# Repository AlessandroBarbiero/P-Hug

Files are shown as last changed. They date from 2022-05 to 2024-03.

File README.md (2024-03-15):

# P'Hug
This repository contains code, wiring schemas, manuals, and a development report on the creation of a wearable robot.  
The delivery was: Make a wearable robot able to engage interactions with third people.

## Abstract
According to surveys and research the haptic sense is a significant aspect of human wellbeing. The experience received as a result of contact with another living creature like hugs stimulates serotonin production. High serotonin levels improve mood, make people feel better, and help having better sleep. Nowadays people are more linked than ever before as a result of the developing trend of technology. While technology has helped to bridge the gap, it has not been able to eliminate all the barriers imposed by distance. Our initiative primarily aims to bridge this gap by creating a product that sends a haptic hug from one device (Giffy: the puppet) to another one (the Jacket). The embrace and caress from the puppet is transfered via a wifi connection to the wearer of the jacket. The wearer can feel three major sensations: vibration achieved by vibration motors simulating a moving caress, pressure from an inflatable chamber simulating a hug, and a constant warm feeling from a resistive wire. Our goal is not to replace an actual embrace, but to help people that live apart and cannot hold their loved ones having a fraction of that so desired contact.

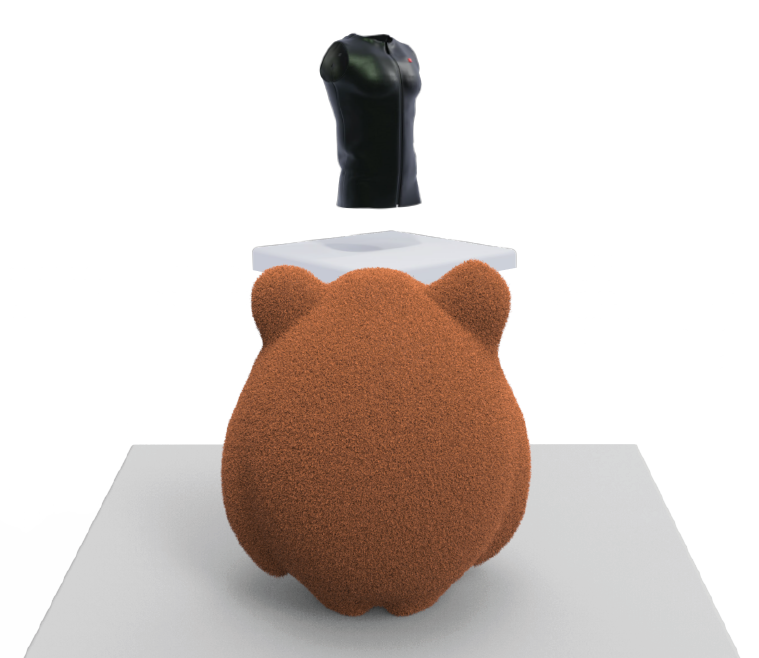
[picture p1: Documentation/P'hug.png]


## More Informations

> P'Hug [Instructions Manual](/Documentation/P'Hug%20Instructions.pdf)

> P'Hug [Maintenance Manual](/Documentation/P'Hug%20Maintenance.pdf)

> Complete [Report](/Documentation/Report%20P'Hug.pdf) of the Development Process

## Electronics organization
Here are reported the wiring schemas for the two devices
### `Giffy`
Built around an `Arduino Mkr1000 wifi`

Input:
- 3 Force sensitive resistors to simulate the caress
- Force sensitive resistor to simulate the hug
- Accelerometer to detect shaking
- NFC reader to upload SSID and Password using the Application

Output:
- 2 Servo motors to move the ears
- Speaker
- Integrated Wifi module (ATSAMW25) of Arduino Mkr1000 wifi

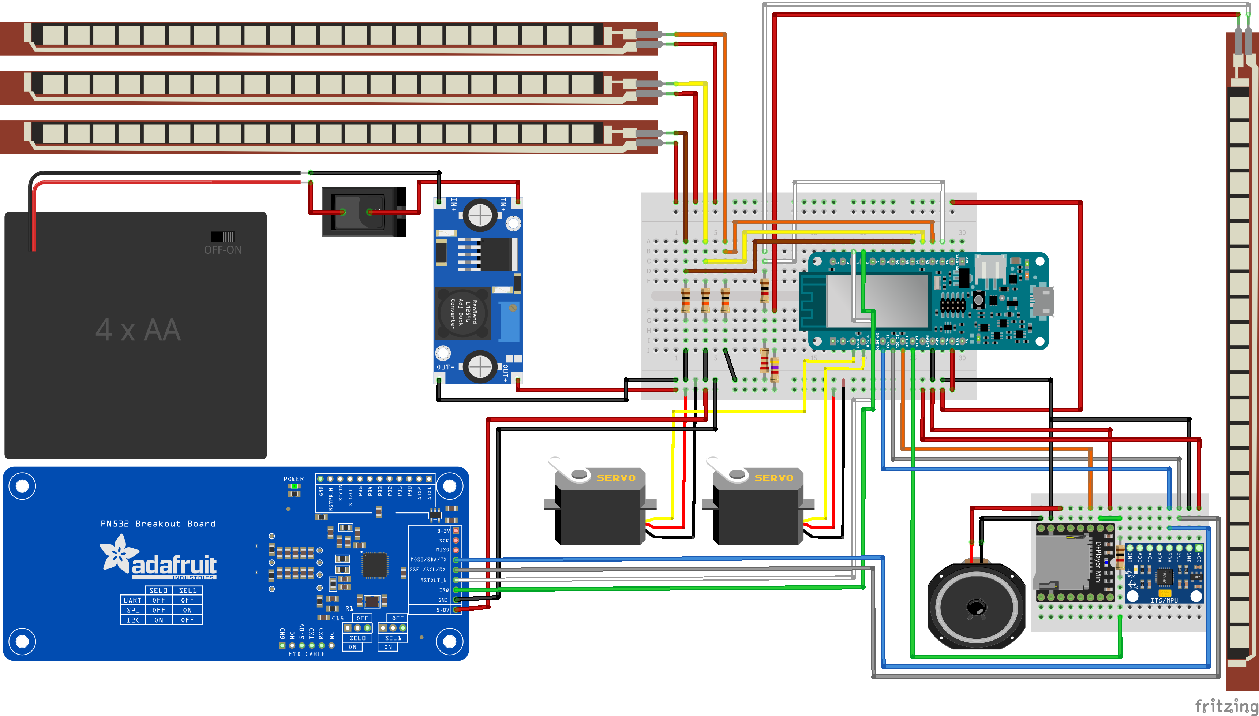
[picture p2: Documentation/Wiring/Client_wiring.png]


##

### `The Jacket`
Built around an `Adafruit Feather Huzzah`

Input:
- Integrated Wifi module (ESP8266) of Adafruit Feather Huzzah 
- Bluetooth module (HC-05) to upload SSID and Password

Output:
- 6 Vibration motors to simulate the caress
- Air pump to inflate the chamber around the waist to simulate the hug
- Heating resistance activated via a relè

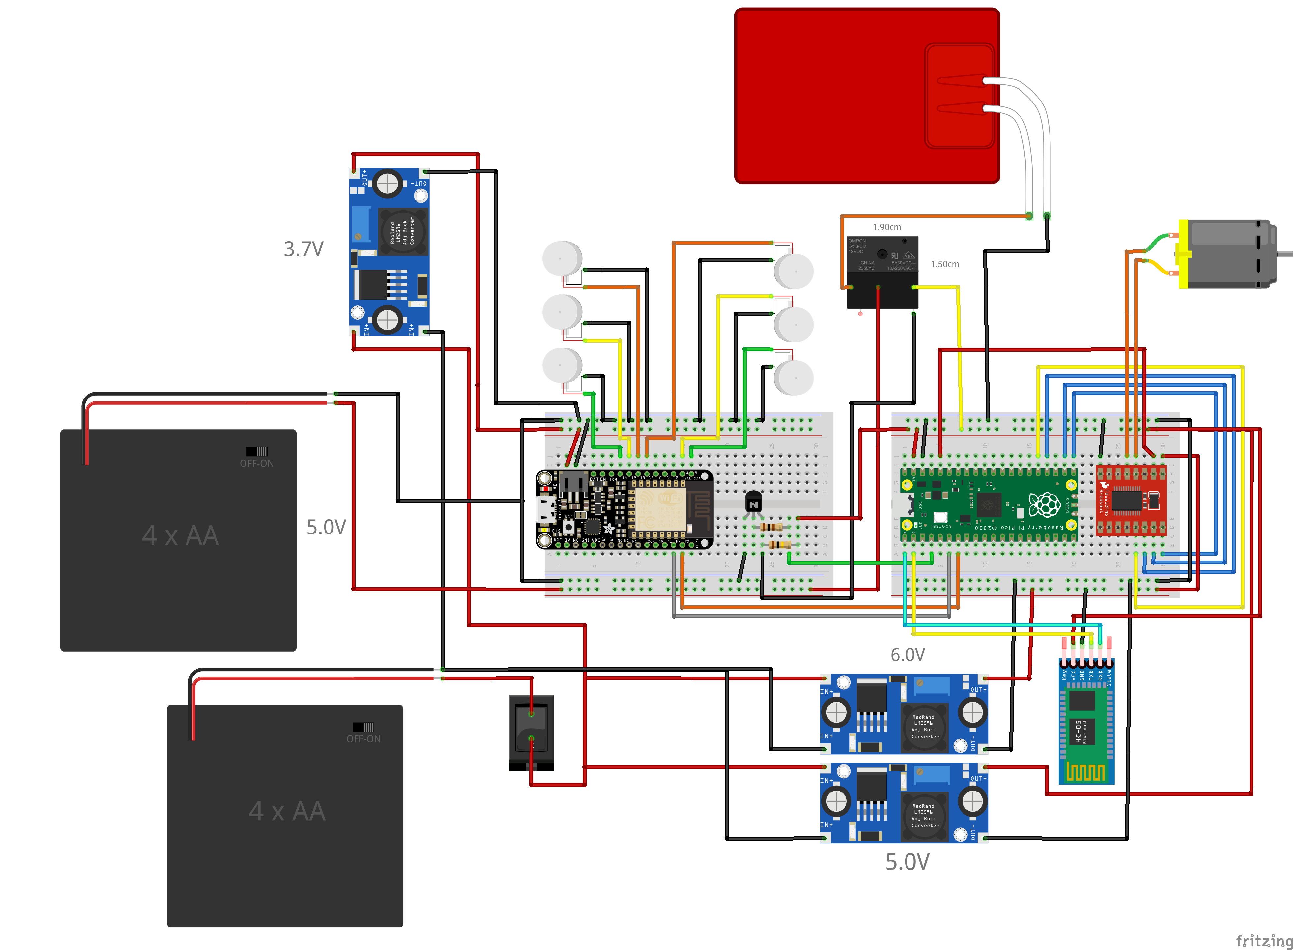
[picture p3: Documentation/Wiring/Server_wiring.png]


## Code organization
All the code has been written following the object oriented programming model with the help of the platform `PlatformIO`.
The main idea is to build a client-server model to receive the information from Giffy and send it to the jacket that operates according to that.

The code can be seen in the folders [Client](/Client/) for Giffy and [Server](/Server/) for the Jacket.

## How to run the project
1. Clone the repository
    ```bash
    git clone https://github.com/AlessandroBarbiero/P-Hug.git
    ```

2. Download an IDE (suggested [PlatformIO](https://platformio.org/) for `Visual Studio Code`).

3. Open the folder [Client](/Client/) or [Server](/Server/Server%20Huzzah/) as `PlatformIO project` from the PlatformIO home.

4. Click on `PlatformIO:upload` on the bottom left.

5. Download the app from the folder [App](/App/) (Read the specific readme for more information about it)

## Team

  

### Engineers

* [__Alessandro Barbiero__](https://github.com/AlessandroBarbiero)
* [__Luigi Altamura__](https://github.com/LuigiAltamura)
* [__Lorenzo Poretti__](https://github.com/lap98)
* [__Elias Insulander__](https://github.com/eliasinsulander)

### Designers

* __Lorenzo Dondi__
* __Helen Berhanu Tekle__

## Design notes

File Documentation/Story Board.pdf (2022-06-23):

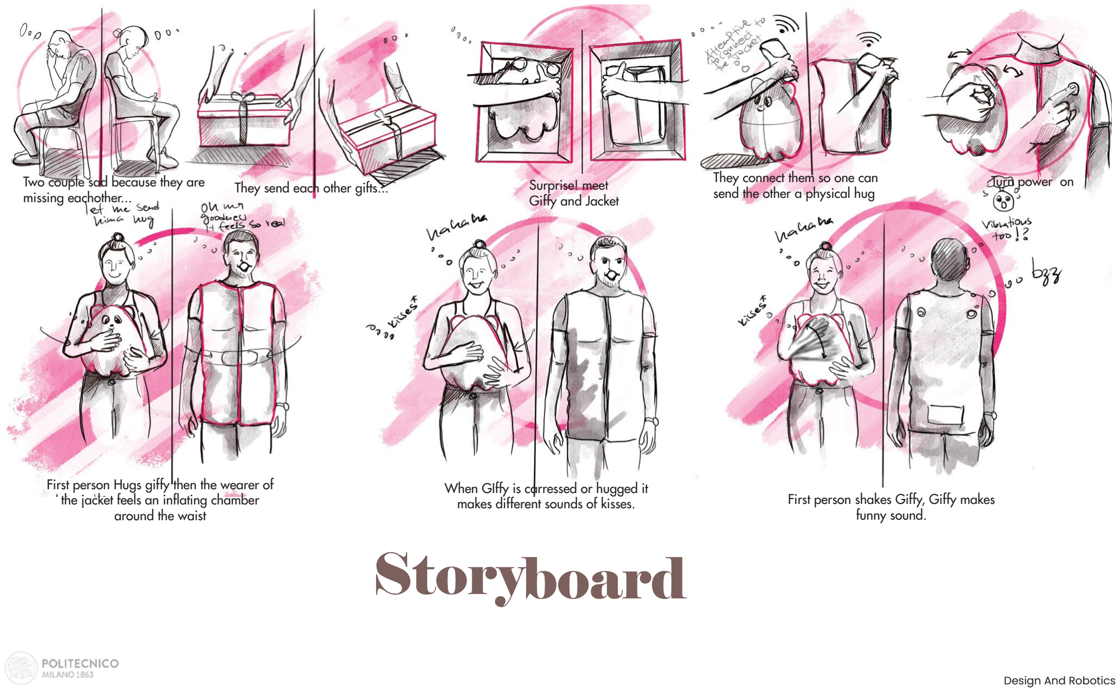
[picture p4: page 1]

# Storyboard

Two couple sad because they are
missing eachother... | They send each other gifts... | Surprise! meet
| | Giffy and Jacket

Turn power on They connect them so one can send the other a physical hug

When GIffy is carressed or hugged it
makes different sounds of kisses. | First person shakes Giffy, Giffy makes
| funny sound.

First person Hugs giffy then the wearer of the jacket feels an inflating chamber around the waist

Design And Robotics

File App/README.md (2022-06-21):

# apP-HUG

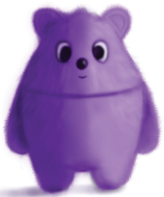
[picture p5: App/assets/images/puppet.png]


apP-HUG is an application to provide network data to Giffy using NFC in an easy way

## Installation

Download the application from this link:

[apP-HUG](https://github.com/AlessandroBarbiero/Robotics-and-Design-project/blob/main/App/APK/apP-HUG.apk)

During installation you may encounter warnings informing you that the application may not be safe. This is because the application is not uploaded to the Google Play Store. 

Accept all the conditions, install it and you now should see a screen like this:

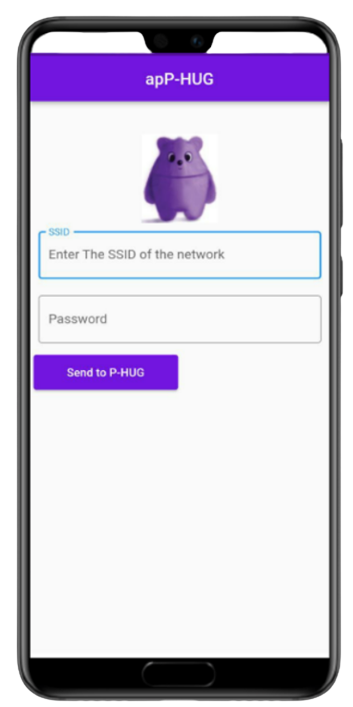
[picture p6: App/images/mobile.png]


## How to use the app 

Before turning on the robot:

- Open the application, activate your hotspot/wifi and NFC in your mobile phone 

- Add SSID of the network in the first text field and the password in the second textfield (username and password have to be maximum 15 characters lenght each)

- Press the send message

- Put your cell phone close to the Giffy's head and wait untill the NFC is red (you should notice a vibration)

Now you are ready! Enjoy GIFFY !!!

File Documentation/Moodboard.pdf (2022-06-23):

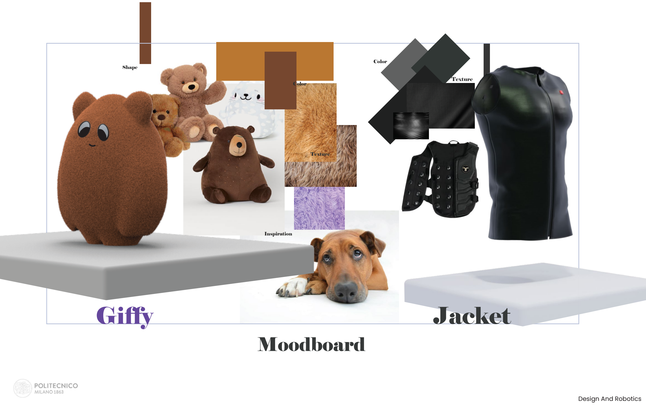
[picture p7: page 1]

Shape

Color

Color

Texture

Texture

# Giffy

Inspiration

# Jacket

# Moodboard

## Design And Robotics

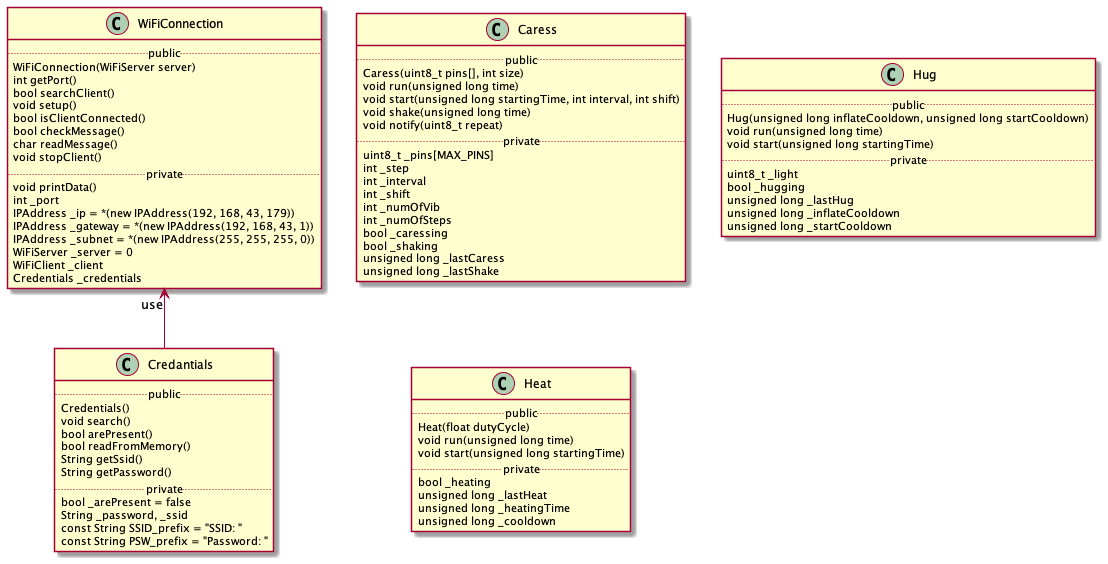
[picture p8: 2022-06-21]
Server/Server Huzzah/diagrams/server.png

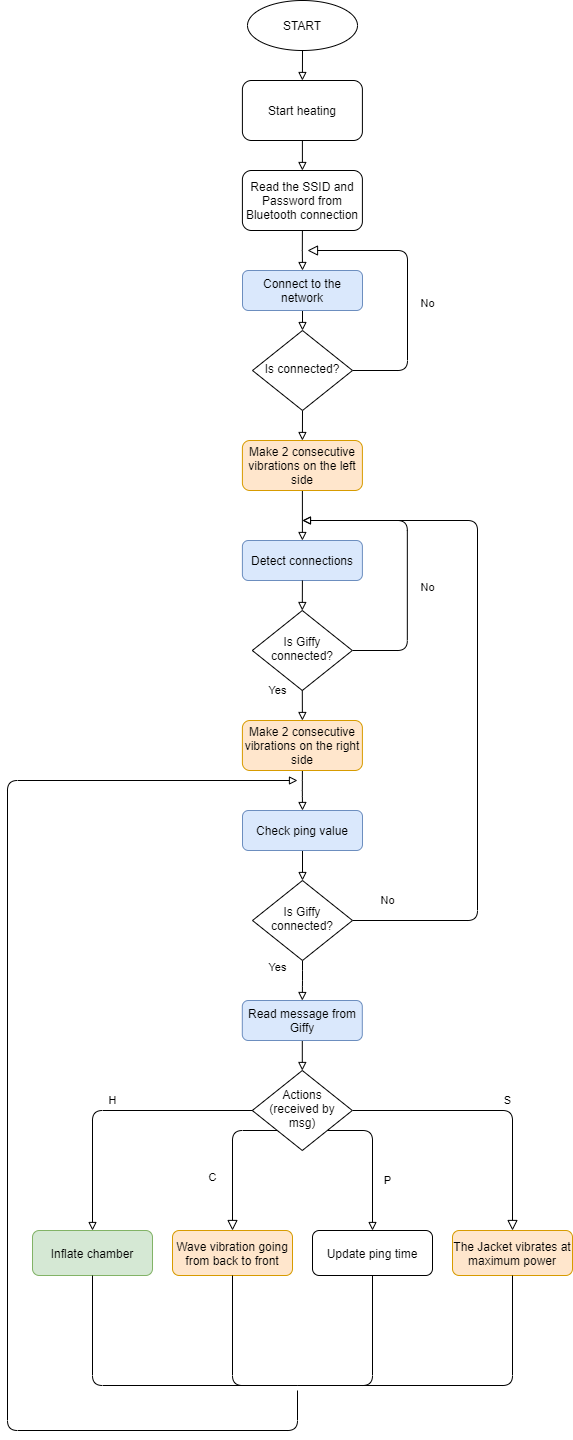
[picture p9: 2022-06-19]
Documentation/Flowchart/Flowchart_Jacket.png

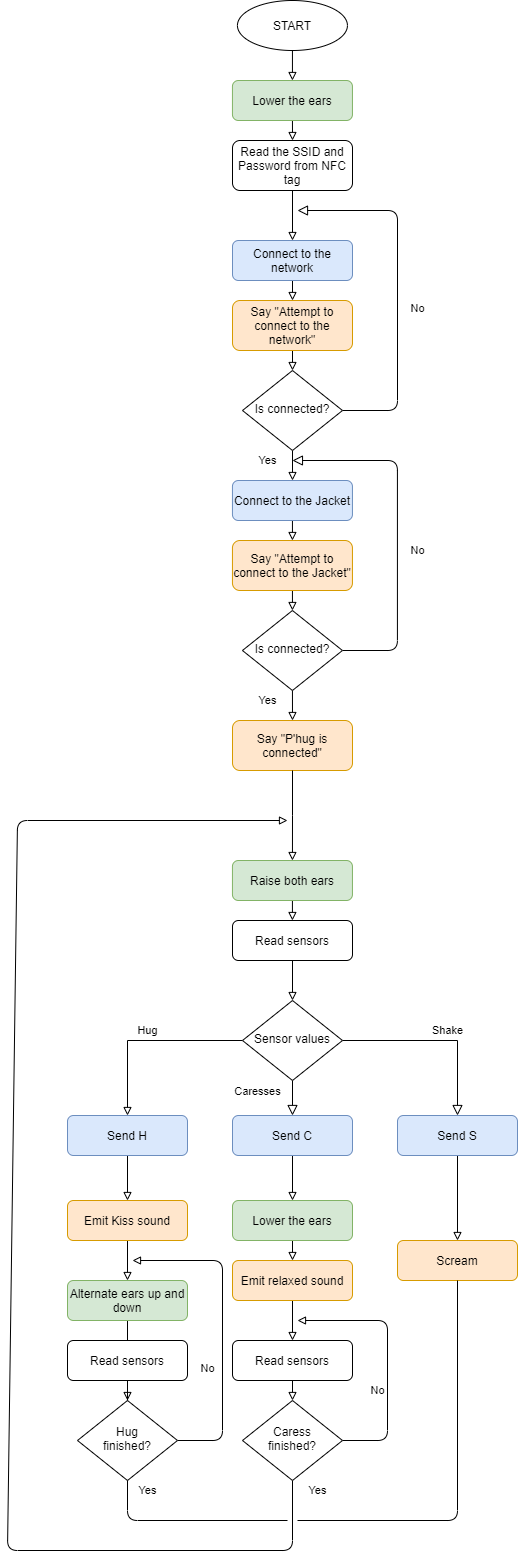
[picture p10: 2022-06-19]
Documentation/Flowchart/Flowchart_Giffy.png

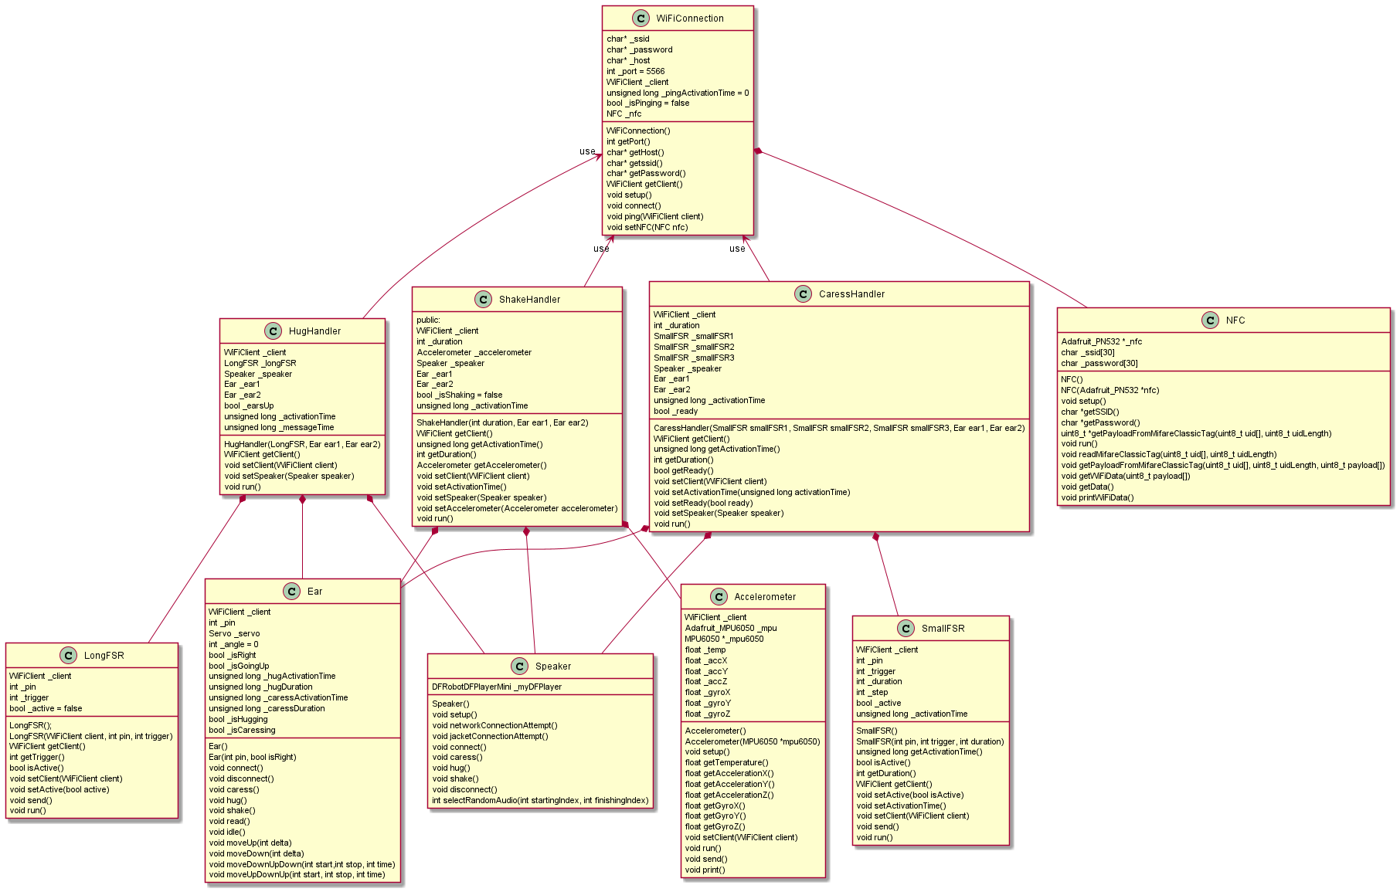
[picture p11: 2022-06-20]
Client/out/diagrams/diagram/diagram.png

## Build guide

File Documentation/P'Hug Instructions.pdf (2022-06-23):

# P-HUG

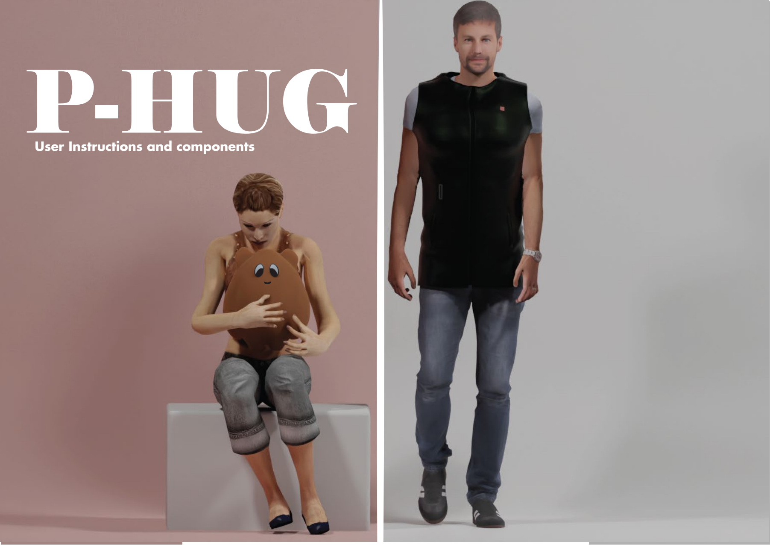
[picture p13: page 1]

## User Instructions and components

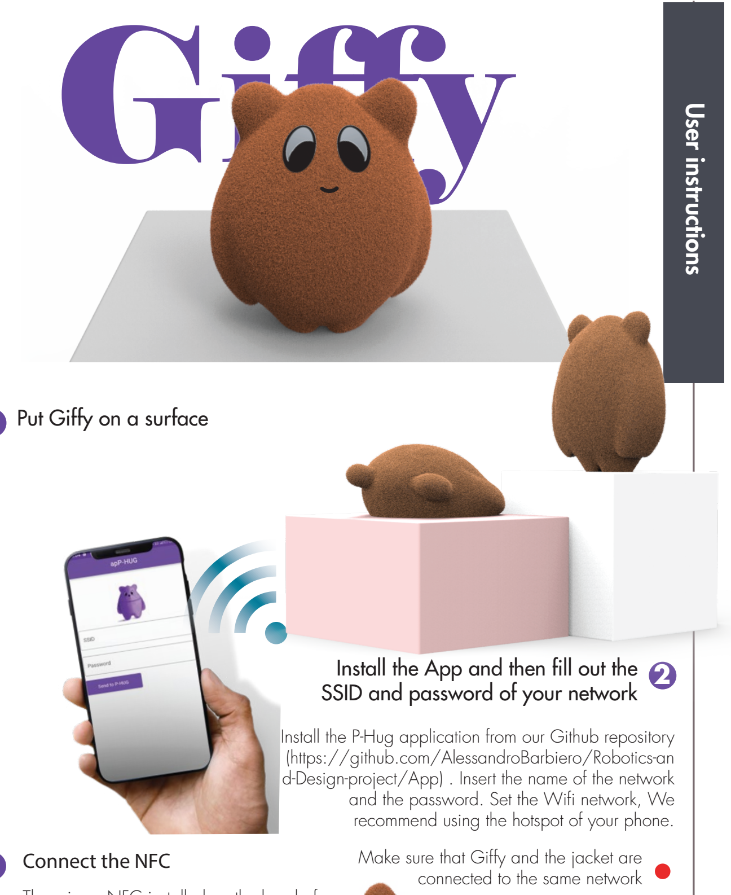
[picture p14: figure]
Giffy; Connect the NFC; Put Giffy on a surface; User instructions; (https://github.com/AlessandroBarbiero/Robotics-an; Make sure that Giffy and the jacket are connected to the same network; Install the App and then fill out the SSID and password of your network

1

3

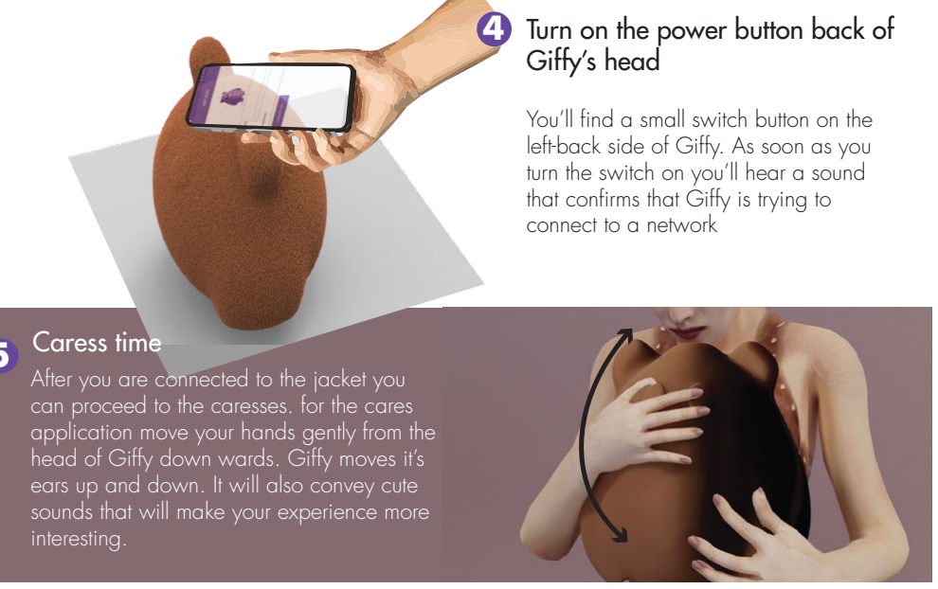
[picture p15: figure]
Turn on the power button back of Giffy’s head; left-back side of Giffy. As soon as you turn the switch on you’ll hear a sound that confirms that Giffy is trying to connect to a network; interesting.; Caress time

You’ll find a small switch button on the

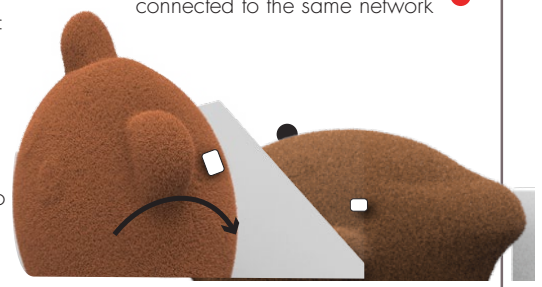
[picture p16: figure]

There is an NFC installed on the head of Giffy. Hoover your smartphone close to Giffy's head, after connecting with the NFC Giffy will make sure that you are connected with the Jacket, you will hear a message that says “attempting to connect with the jacket”. You will listen to a sound that says “P-Hug is connected”

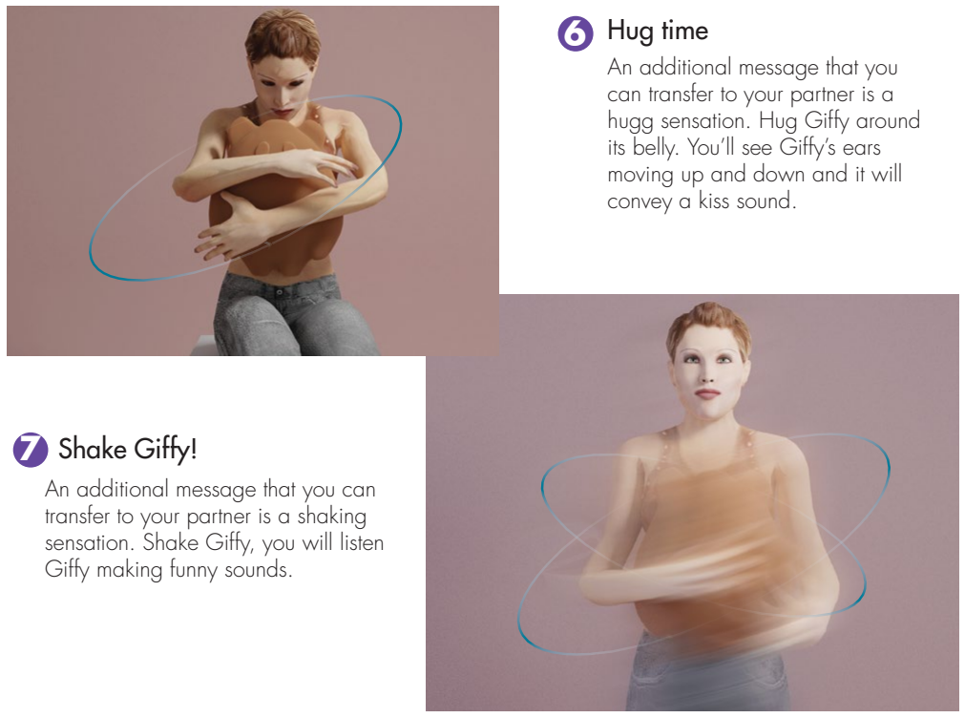
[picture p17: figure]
An additional message that you can transfer to your partner is a hugg sensation. Hug Giffy around its belly. You’ll see Giffy’s ears moving up and down and it will convey a kiss sound.; An additional message that you can transfer to your partner is a shaking sensation. Shake Giffy, you will listen Giffy making funny sounds.; Hug time; Shake Giffy!

# Design And Robotics

5
After you are connected to the jacket you can proceed to the caresses. for the cares application move your hands gently from the head of Giffy down wards. Giffy moves it’s ears up and down. It will also convey cute sounds that will make your experience more

Install the P-Hug application from our Github repository

d-Design-project/App) . Insert the name of the network and the password. Set the Wifi network, We recommend using the hotspot of your phone.

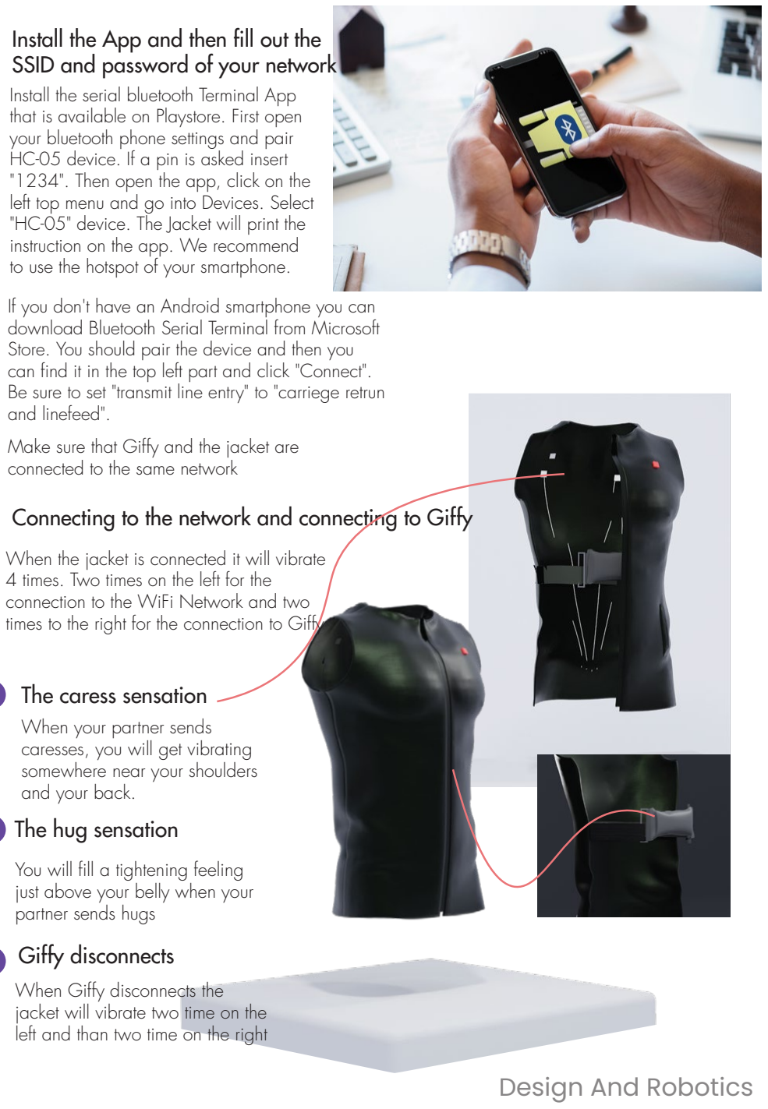
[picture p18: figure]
SSID and password of your network; Make sure that Giffy and the jacket are connected to the same network; When Giffy disconnects the jacket will vibrate two time on the left and than two time on the right; 4 times. Two times on the left for the connection to the WiFi Network and two
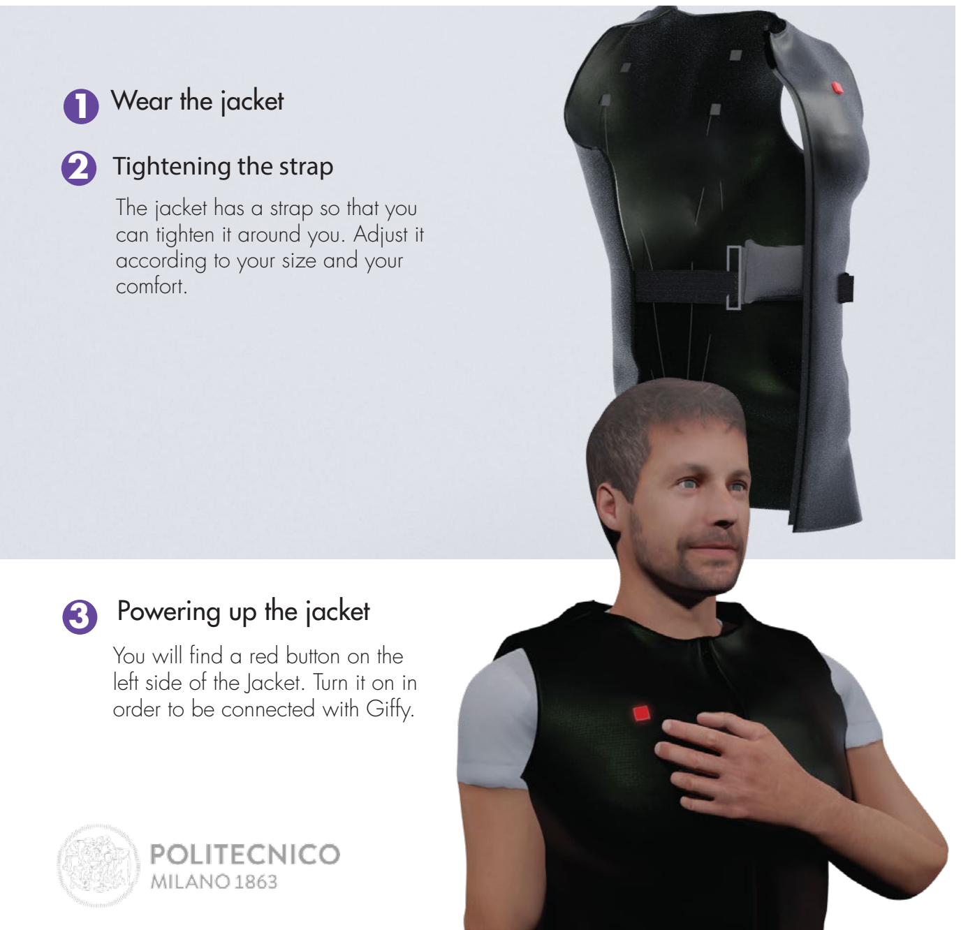
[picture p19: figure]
Powering up the jacket; Wear the jacket; The jacket has a strap so that you can tighten it around you. Adjust it according to your size and your comfort.; You will find a red button on the left side of the Jacket. Turn it on in order to be connected with Giffy.; 2 Tightening the strap 13

When your partner sends
caresses, you will get vibrating somewhere near your shoulders and your back.

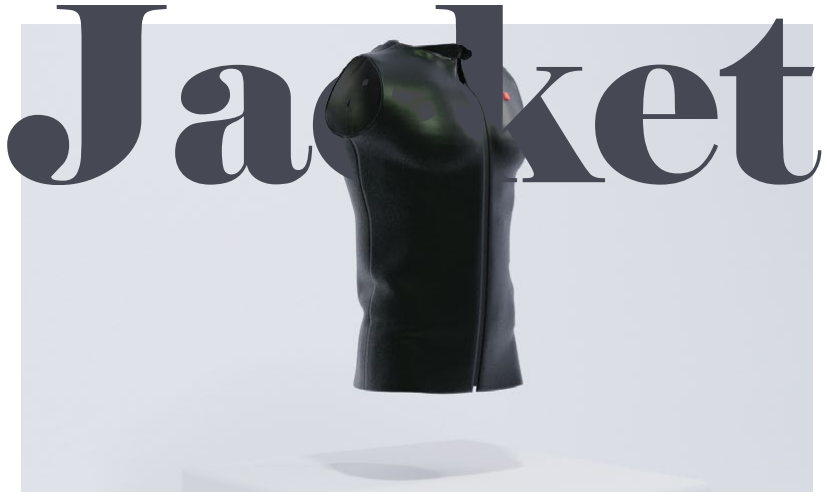
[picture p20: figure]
Jacket

## User instructions

### The hug sensation

### Giffy disconnects

You will fill a tightening feeling just above your belly when your partner sends hugs

### 6 The caress sensation

### Connecting to the network and connecting to Giffy

78

Install the serial bluetooth Terminal App that is available on Playstore. First open your bluetooth phone settings and pair HC-05 device. If a pin is asked insert "1234". Then open the app, click on the left top menu and go into Devices. Select "HC-05" device. The Jacket will print the instruction on the app. We recommend
to use the hotspot of your smartphone.

If you don't have an Android smartphone you can download Bluetooth Serial Terminal from Microsoft Store. You should pair the device and then you can find it in the top left part and click "Connect". Be sure to set "transmit line entry" to "carriege retrun and linefeed".

### Install the App and then fill out the

45

When the jacket is connected it will vibrate

times to the right for the connection to Giffy

Giffy Components | Description

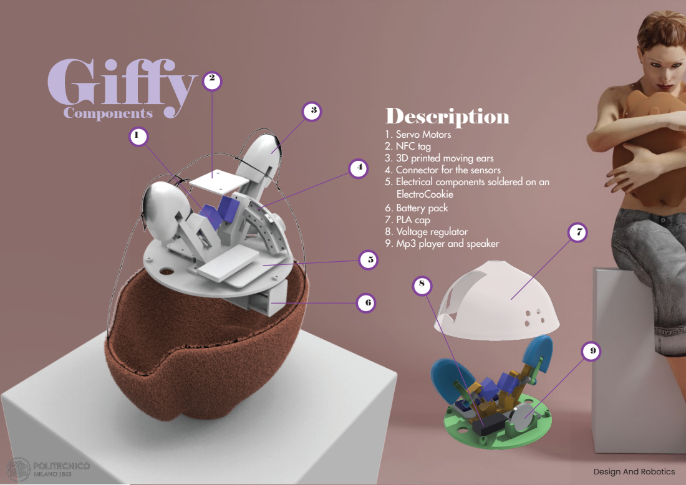
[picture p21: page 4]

1. Servo Motors
2. NFC tag
3. 3D printed moving ears
4. Connector for the sensors
5. Electrical components soldered on an
ElectroCookie
6. Battery pack
7. PLA cap
8. Voltage regulator
9. Mp3 player and speaker

# Jacket

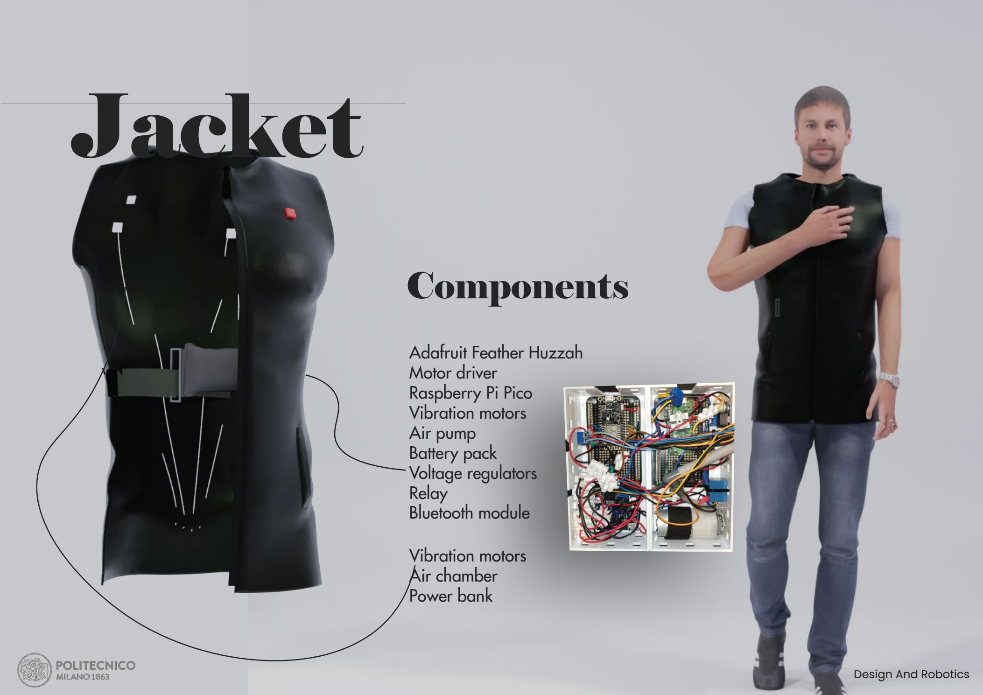
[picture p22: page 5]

## Vibration motors Air chamber Power bank

# Components

## Adafruit Feather Huzzah Motor driver Raspberry Pi Pico Vibration motors Air pump Battery pack Voltage regulators Relay Bluetooth module

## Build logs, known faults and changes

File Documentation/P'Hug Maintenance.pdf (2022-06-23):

# P’Hug - Maintenance instructions

Below, you can find some maintenance instructions if there is an issue with either the puppet or the jacket. Most parts can be replaced and these parts are connected to the respective boards via wire connectors that can be tightened/loosened using a screwdriver. If a part needs further instructions for replacement it is specified under “Specific parts”.

## Giffy

For all Giffy part replacements and access to the board:
1. Open the zip on the back of the puppet
2. Remove the soft stuffing inside the puppet
3. Carefully pull out the long force sensor from the guides
4. Carefully take out the head of the puppet with all of the electronics
5. Perform the required maintenance
6. Carefully put everything back in the puppet (reverse steps 1-4)

### Power

Replacing the batteries of the puppet can be done without removing the puppets head from the puppets body. In order to change the batteries of Giffy:
1. Pull out the battery pack on the bottom of the head
2. Remove the 4 AA-batteries from the battery pack
3. Insert new batteries in the battery pack
4. Reinsert battery pack into the holder on the bottom of the head

### Part replacement

For all part replacements:
1. Remove the three screws fixing the dome to the plate of the head
2. Disassemble the ears by separating the two ear parts (one ear could be enough, but easier with both removed)
3. Remove the dome from the plate
4. Disconnect the wires for the desired part
5. Connect new part
6. Reassemble the head (reverse steps 1-3)

Specific parts:
The servo motors, the speaker and the NFC are all soldered directly to the board, and in order to change these parts resoldering is necessary.

### Access to board

To access the board in order to upload code and/or debug:
1. Remove the three screws fixing the dome to the plate of the head
2. Disassemble the ears by separating the two ear parts (one ear could be enough, but easier with both removed)
3. Remove the dome from the plate
4. Connect a Micro-USB cable to the Arduino MKR1000
5. Upload/debug code
6. Disconnect the Micro-USB cable
7. Reassemble the head (reverse steps 1-3)

## Jacket

For all jacket part replacements and access to the boards:
1. Remove the bands over the box on the back of the jacket
2. Carefully pull the wires connected to the box out from the jacket slightly
3. Remove the smaller elastic bands around the box
4. Remove the plate from the box and turn the box so that the electronics are exposed.
5. Perform the required maintenance
6. Put everything back in its place (reverse steps 1-4)

### Power

In the left hand pocket of the jacket there is a USB-connected power bank. This power bank can be recharged and/or replaced with another power bank of the same characteristics. The power bank is used only to power the heating part of the jacket, you can easily disconnect this power bank in order to not feel the heating sensation. The maximum current allowed is 2.1A, and we are using a power bank with capacity of 16750mAh.

In the right hand pocket of the jacket there is a battery pack. It powers all the electronics. In order to change the batteries of the battery pack:
1. Take the battery pack out of the pocket
2. Open the battery pack
3. Remove the 4 AA-batteries
4. Insert new batteries in the battery pack
5. Close the battery pack
6. Reinsert the battery pack into the pocket

### Part replacement

For all part replacements:
1. Disconnect the wires for the desired part
2. Connect new part

Specific parts:
The vibration motors are sewn onto the inside of the jacket and must be detached and resewn in order to replace them. They can be easily accessed via the zips on the inside of the jacket.

The air pump and air chamber was originally from a sphygmomanometer and we don’t recommend that they be changed, as the code is tuned specifically for this air pump and this air chamber.

We also don’t recommend that you replace the heating system, as it was integrated in the jacket when we received it.

### Access to boards

The Micro-USB ports of the two boards are easily accessible even when the box is closed, though it is recommended to open the box when uploading or debugging code.
1. Connect a Micro-USB cable to the Adafruit Feather HUZZAH and/or the Raspberry Pi Pico
a. If code has to be uploaded to the Adafruit Feather HUZZAH, also disconnect one of the serial communication wires (TX) connected to the Raspberry Pi Pico (the gray one) unscrewing the screw on the connector
2. Upload/debug code
a. If code was uploaded to the Adafruit Feather HUZZAH, also reconnect the serial communication wire to the Raspberry Pi Pico
3. Disconnect the Micro-USB cable

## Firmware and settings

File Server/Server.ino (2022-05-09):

#include "arduino_secrets.h"
#include <ESP8266WiFi.h>

// Define Pins
#define VIB1 14
#define VIB2 12
#define VIB3 13
#define MAX 255
#define BUTTON A0
#define COOLDOWN 10000
#define INTERVAL 510
#define HINTERVAL 255
#define SHIFT 255
#define NROFVIB 3
int val,i;
unsigned long lastCaress,lastHug;
bool caressing,hugging;

///////please enter your sensitive data in the Secret tab/arduino_secrets.h
char ssid[] = SECRET_SSID;        // your network SSID (name)
char pass[] = SECRET_PASS;    // your network password (use for WPA, or use as key for WEP)
int status = WL_IDLE_STATUS;     // the Wifi radio's status
// mac address for M-Duino

int data = 0;
int tcp_port = 5566;
IPAddress ip(192, 168, 43, 179); 
IPAddress gateway(192, 168, 43, 1);
IPAddress subnet(255, 255, 255, 0);
WiFiServer server(tcp_port);
void setup() {
  //Vibration init
  pinMode(VIB1, OUTPUT);
  pinMode(VIB2, OUTPUT);
  pinMode(VIB3, OUTPUT);
  pinMode(0, OUTPUT);
  digitalWrite(0, HIGH);
  Serial.begin(9600);
  lastCaress = 0;
  caressing = false;
  hugging = false;
  
  //Initialize serial and wait for port to open:
  Serial.begin(9600);

  WiFi.config(ip, gateway, subnet);
  while (!Serial);
  
  // attempt to connect to Wifi network:
  while (status != WL_CONNECTED) {
    Serial.print("Attempting to connect to network: ");
    Serial.println(ssid);
    // Connect to WPA/WPA2 network:
    status = WiFi.begin(ssid, pass);

    // wait 10 seconds for connection:
    delay(10000);
    
  }
  
  server.begin();

  

  // you're connected now, so print out the data:
  Serial.println("You're connected to the network and Server started");
  
  Serial.println("----------------------------------------");
  printData();
  Serial.println("----------------------------------------");
}

void loop() {
  // check the network connection once every 10 seconds:
 //delay(1000);
 //printData();
 //Serial.println("----------------------------------------");

  WiFiClient client = server.available();
  if (client) {
    Serial.println("new client");
    
    while (client.connected()) {
      if (client.available()) {
        char c = (char) client.read();
        Serial.print("Message: ");
        Serial.println(c);
        if(c=='c'){
          caress();
          }
         else if(c== 'h'){
          hug();
          }
        
        }
       if (caressing){
          
          if(i< INTERVAL){
              analogWrite(VIB1, i);
              }
            else if(i<INTERVAL*2){
              analogWrite(VIB1, INTERVAL*2-i);
              }
            
            if(i>SHIFT && i<SHIFT+INTERVAL){
              analogWrite(VIB2, i-SHIFT);
              }
            else if(i>SHIFT+INTERVAL && i<SHIFT+2*INTERVAL){
              analogWrite(VIB2, SHIFT+2*INTERVAL-i);
              }
      
            if(i>2*SHIFT && i<2*SHIFT+INTERVAL){
              analogWrite(VIB3, i-2*SHIFT);
              }
            else if(i>2*SHIFT+INTERVAL && i<2*SHIFT+2*INTERVAL){
              analogWrite(VIB3, 2*SHIFT+2*INTERVAL-i);
              }
      
              i++;
              delay(1);
              if(i == (SHIFT+INTERVAL)*(NROFVIB-1)){
                caressing = false;
                i=0;
                }
        }

        if(hugging){
          digitalWrite(0, LOW);
          delay(1000);
          digitalWrite(0, HIGH);
          hugging = false;
          }
      }

      delay(1000);
    }
    // give the web browser time to receive the data
    
  
    // close the connection:
    //client.stop();
    //Serial.println("client disonnected");
}


void printData() {
  Serial.println("Board Information:");
  // print your board's IP address:
  IPAddress ip = WiFi.localIP();
  Serial.print("IP Address: ");
  Serial.println(ip);

  Serial.println();
  Serial.println("Network Information:");
  Serial.print("SSID: ");
  Serial.println(WiFi.SSID());
}

void caress(){
  if(millis()- lastCaress > COOLDOWN){
    Serial.println("Caress started at time: ");
    
    lastCaress = millis();

    Serial.println(lastCaress);

   caressing = true;
    
  }
}

void hug(){
  if(millis()- lastHug > COOLDOWN){
    Serial.println("Hug started at time: ");
    
    lastHug = millis();

    Serial.println(lastHug);

   hugging = true;
    
  }
  }

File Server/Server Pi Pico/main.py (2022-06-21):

from machine import UART, Pin, PWM
import utime
import os

def detectMessage(message):
    
    str = message.decode('utf-8', 'ignore')

    msg = str.split(" ")
        
    if(msg[0] == "R:"):
        
        print(message)
        if(msg[1] == 'w'):
            
            jacket.value(int(msg[2]))
        
        if(msg[1] == 'h'):
            
            controlHugMotor(int(msg[2]))

    return("other input")




def controlHugMotor(controlValue):
    
     if controlValue == 0:
        stby.value(0)
        ina1.value(0)
        ina2.value(0)
        pwma.duty_u16(0)
     else:
        stby.value(1)
        ina1.value(1)
        ina2.value(0)
        pwma.duty_u16(65536)
        
     return
    
def readFromFile():
    
    with open('credentials.txt', 'a') as f:
        lines = f.readlines()
        

    # Strips the newline character
    if(len(lines) >= 2):
        uart1.write(lines[0])
        utime.sleep(2)
        uart1.write(lines[1])
        print(lines)
    else:
        uart1.write('Empty')
        print('Empty')


def writeFile(credentials):
    
    with open('credentials.txt', 'a') as f:
        f.write(credentials[0])
        f.write(credentials[1])


def deleteFile():
    
    with open('credentials.txt', 'w') as f:
        f.close()
        
    
    
jacket = Pin(2,Pin.OUT)
stby = Pin(19, Pin.OUT)
ina1 = Pin(18, Pin.OUT)
ina2 = Pin(17, Pin.OUT)
pwma = PWM(Pin(16))
pwma.freq(65535)

wifiRead = True
led = Pin(25, Pin.OUT)
firstTime = True
firstAttempt = True
jacket.value(1)
searchFlag = False
#utime.sleep(5)
print("Ready to go")

led.value(1)

uart = UART(0, baudrate=9600)
uart1 = UART(1, baudrate=9600)


#uart.write('Please insert Network name and Password')
while(wifiRead):
    #print('checking BT')
    if uart1.any():
        try:
            command = uart1.readline()
        except:
            continue
        
        if(command != None):
            try: 
                str = command.decode('utf-8', 'ignore')  
            except:
                continue
            
            
            msg = str.split(" ")

            if(msg[0] == "R:"):
                msg[1] = msg[1].replace("\r\n", "")
                print(msg[1])
                if(msg[1] == 'read'):
                    #uart.write('Reading credentials from memory. Please wait!\n')
                    readFromFile()
                    
                if(msg[1] == 'success'):
                    if (searchFlag):
                        writeFile(credentials)
                    wifiRead = False
                    uart.write('Success')
                    print(msg[1])
                    
                if(msg[1] == 'search'):
                    searchFlag = True
                    deleteFile()
                    if(firstAttempt):
                        uart.write('Please insert Network name \n')
                    else:
                        uart.write('SSID or password not correct!\n Please insert Network name again \n')
                    firstTime = True
                    print(msg[1])

    if uart.any():
        
        try:
            command = uart.readline()
        except:
            continue
        
        #print(command)
        if(command != None):
            try:
                str = command.decode('utf-8', 'ignore')
            except:
                continue
            
            #print(str)
            if(firstTime):
                credentials = []
                str = 'SSID: ' + str
                credentials.append(str)
                uart1.write(str)
                print(str)
                firstTime = False
                if(firstAttempt):
                    uart.write('Please insert password \n')
                else:
                    uart.write('Please insert password again \n')
            else:
                str = 'Password: ' + str
                credentials.append(str)
                uart1.write(str)
                print(str)
                firstTime = True
                
                if(firstAttempt):
                    uart.write('Attempting to connect to the network \n')
                    firstAttempt = False
                else:
                    uart.write('Attempting to connect to the network \n')
                    
                utime.sleep(1)
       
    utime.sleep(1)
    
print('Ready for the jacket')

while True:
    
    try:
        message = uart1.readline()
        if(message != None):
        
            detectMessage(message)
        
        utime.sleep(0.2)
    except:
        jacket.value(0)
        controlHugMotor(0)
        continue

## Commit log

2022-05-10 Fix bug of SPI library
    [Client.cpp]
2022-05-10 Integrated hug and caress (+button support)
2022-05-10 fix bug in client constructor
    [Client.cpp]
2022-05-14 Update the code with the new sensor
2022-05-14 Move set client in the correct position
    [Client.cpp]
2022-05-15 Add Accelerometer class
2022-05-15 Add main functions to accelerometer
2022-05-16 Add accelerometer inside main
2022-05-17 Added some pins for vibration motors
    [main.cpp]
2022-05-19 Modify Accelerometer class
2022-05-24 Add: Communication between server and the pico
2022-05-24 Add Heat class, try in debug to build two caresses, change messages according to communication paradigm, removed the warning for the wifiConnection
2022-05-24 Removed integrated light from Heat, cleaned comments
2022-05-29 Synchronized all the calls to funcrtion in the main passing the same time, Add client wiring diagram
    [client_wiring.fzz]
2022-05-29 Add Server wiring first draft
    [Server_wiring.fzz]
2022-05-29 Find bug in the accelerometer
    [Client.cpp]
2022-05-30 Add duty cycle to Heat
2022-05-31 Changed heat frequency
    [Server_wiring.fzz]
2022-05-31 Upload wirings diagram of server
    [Server_wiring.fzz]
2022-05-31 fix caress code and test it, add shake function
    [Server_wiring.fzz]
2022-06-03 Fix bug of accelerometer
    [Client.cpp]
2022-06-05 Adjust accelerometer trigger according to the new library
2022-06-07 Added file for the Raspberry Pi Pico (Server)
2022-06-07 Add 1s timer to ping
2022-06-07 Longer cooldown for air pump
2022-06-11 Update Server_wiring with new alimentations
    [Server_wiring.fzz]
2022-06-12 Refactor Client wiring names
    [client_wiring.fzz]
2022-06-12 Add switch into Client wiring schema
    [Client_wiring.fzz]
2022-06-15 Fix ear bug during caressing
    [Client.cpp]
2022-06-18 Change wiring diagrams: add nfc to client, correct serial communication
    [Client_wiring.fzz, Server_wiring.fzz]
2022-06-18 Pico code with try catch and name change
2022-06-19 Add flowcharts
2022-06-19 Add flowchart and move directories
    [Client_wiring.fzz, Server_wiring.fzz]
2022-06-19 Flowcharts updates
2022-06-19 modify code to reduce power consumption over the network
2022-06-19 Update flowchart
2022-06-20 fix bug in the first caress
    [Client.cpp]
2022-06-21 Added new code of pi pico
2022-06-21 Solved bug with caress
    [server.cpp]
2022-06-23 Add documents
    [Server_wiring.fzz]
